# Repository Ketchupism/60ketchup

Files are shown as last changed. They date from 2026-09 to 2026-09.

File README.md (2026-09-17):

# 60ketchup
60% keyboard gasket-mount with hot-swaps

most effort-keyboard project I made

- 61 keys (number keys, no arrows keys)
- hot-swaps
- gasket-mount

I started with project somewhat weeks ago after finishing my first keyboard. There was so many improvements and changes I could of make if I made another keyboard. I tried to make a curved Alice, split wired keyboard. Unfortunately, I ended up with not many days to work on it and time was running out before the program ended. I had to edit my schematics and PCB to fit the new keyboard criteria. I spent the rest of the days just then working on the PCB and github. 

Overall, this project was fun and gave me opportunities to practice and learn using Fusion360 and KiCad and the general understanding of how keyboards are made. Learning how to create a keyboard and having a finished product that I was satisfied with was really nice. Some of the things that were a huge process or took a long time to learn / work on was reediting work to a new keyboard layout, tracing all my components, learning how to create a gasket mount that was stable, and creating my bill of materials list. My files are found in PCB and KiCad. 





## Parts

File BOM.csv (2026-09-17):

Item Number | Part Name | rough price(CAD) | Source
1 | Raspberry Pi Pico | $10 | https://www.aliexpress.com/item/1005012636772410.html
2 | Akko Bittersweet Switches | $40 | https://en.akkogear.com/product/bittersweet-switch-lubed/?wmc-currency=CAD
3 | Keebox Poron Gasket Stripes | $17 | https://www.aliexpress.com/item/1005011981917436.html?curPageLogUid=iiTFOxfWYzAK
4 | Diodes 1N4148 | $3 | https://www.aliexpress.com/item/1005004103990376.html?curPageLogUid=qKCPQEb689cl
5 | PCB | $50 | no link and manufacturer is JLCPCB
6 | Keycaps | $45 | https://www.aliexpress.com/item/1005008964445396.html?curPageLogUid=tNXORQnz6FKv
7 | Pre-lubed stabilizers | $8 | https://www.aliexpress.com/item/1005010788206824.html?curPageLogUid=R08arJvPWrKm
8 | TOTAL | $173CAD (~130USD) | N/A

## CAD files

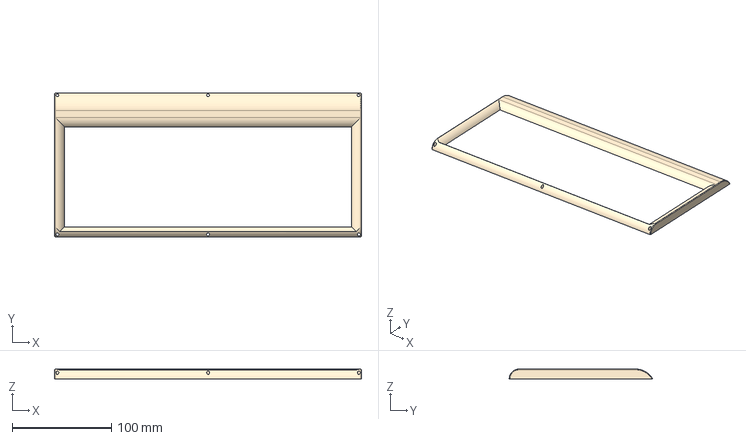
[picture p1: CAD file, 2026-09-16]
CAD/top_case.step
310.0 x 145.0 x 10.0 mm

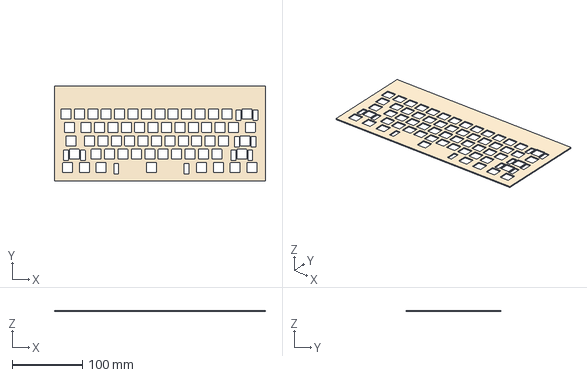
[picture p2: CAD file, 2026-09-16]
CAD/plate.step
300.0 x 135.0 x 1.50 mm

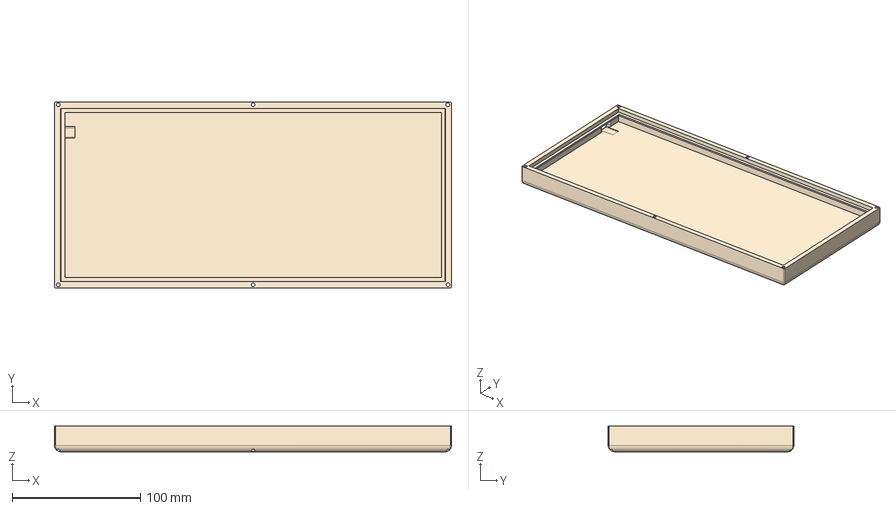
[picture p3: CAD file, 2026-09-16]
CAD/bottom_case.step
310.0 x 145.0 x 20.0 mm

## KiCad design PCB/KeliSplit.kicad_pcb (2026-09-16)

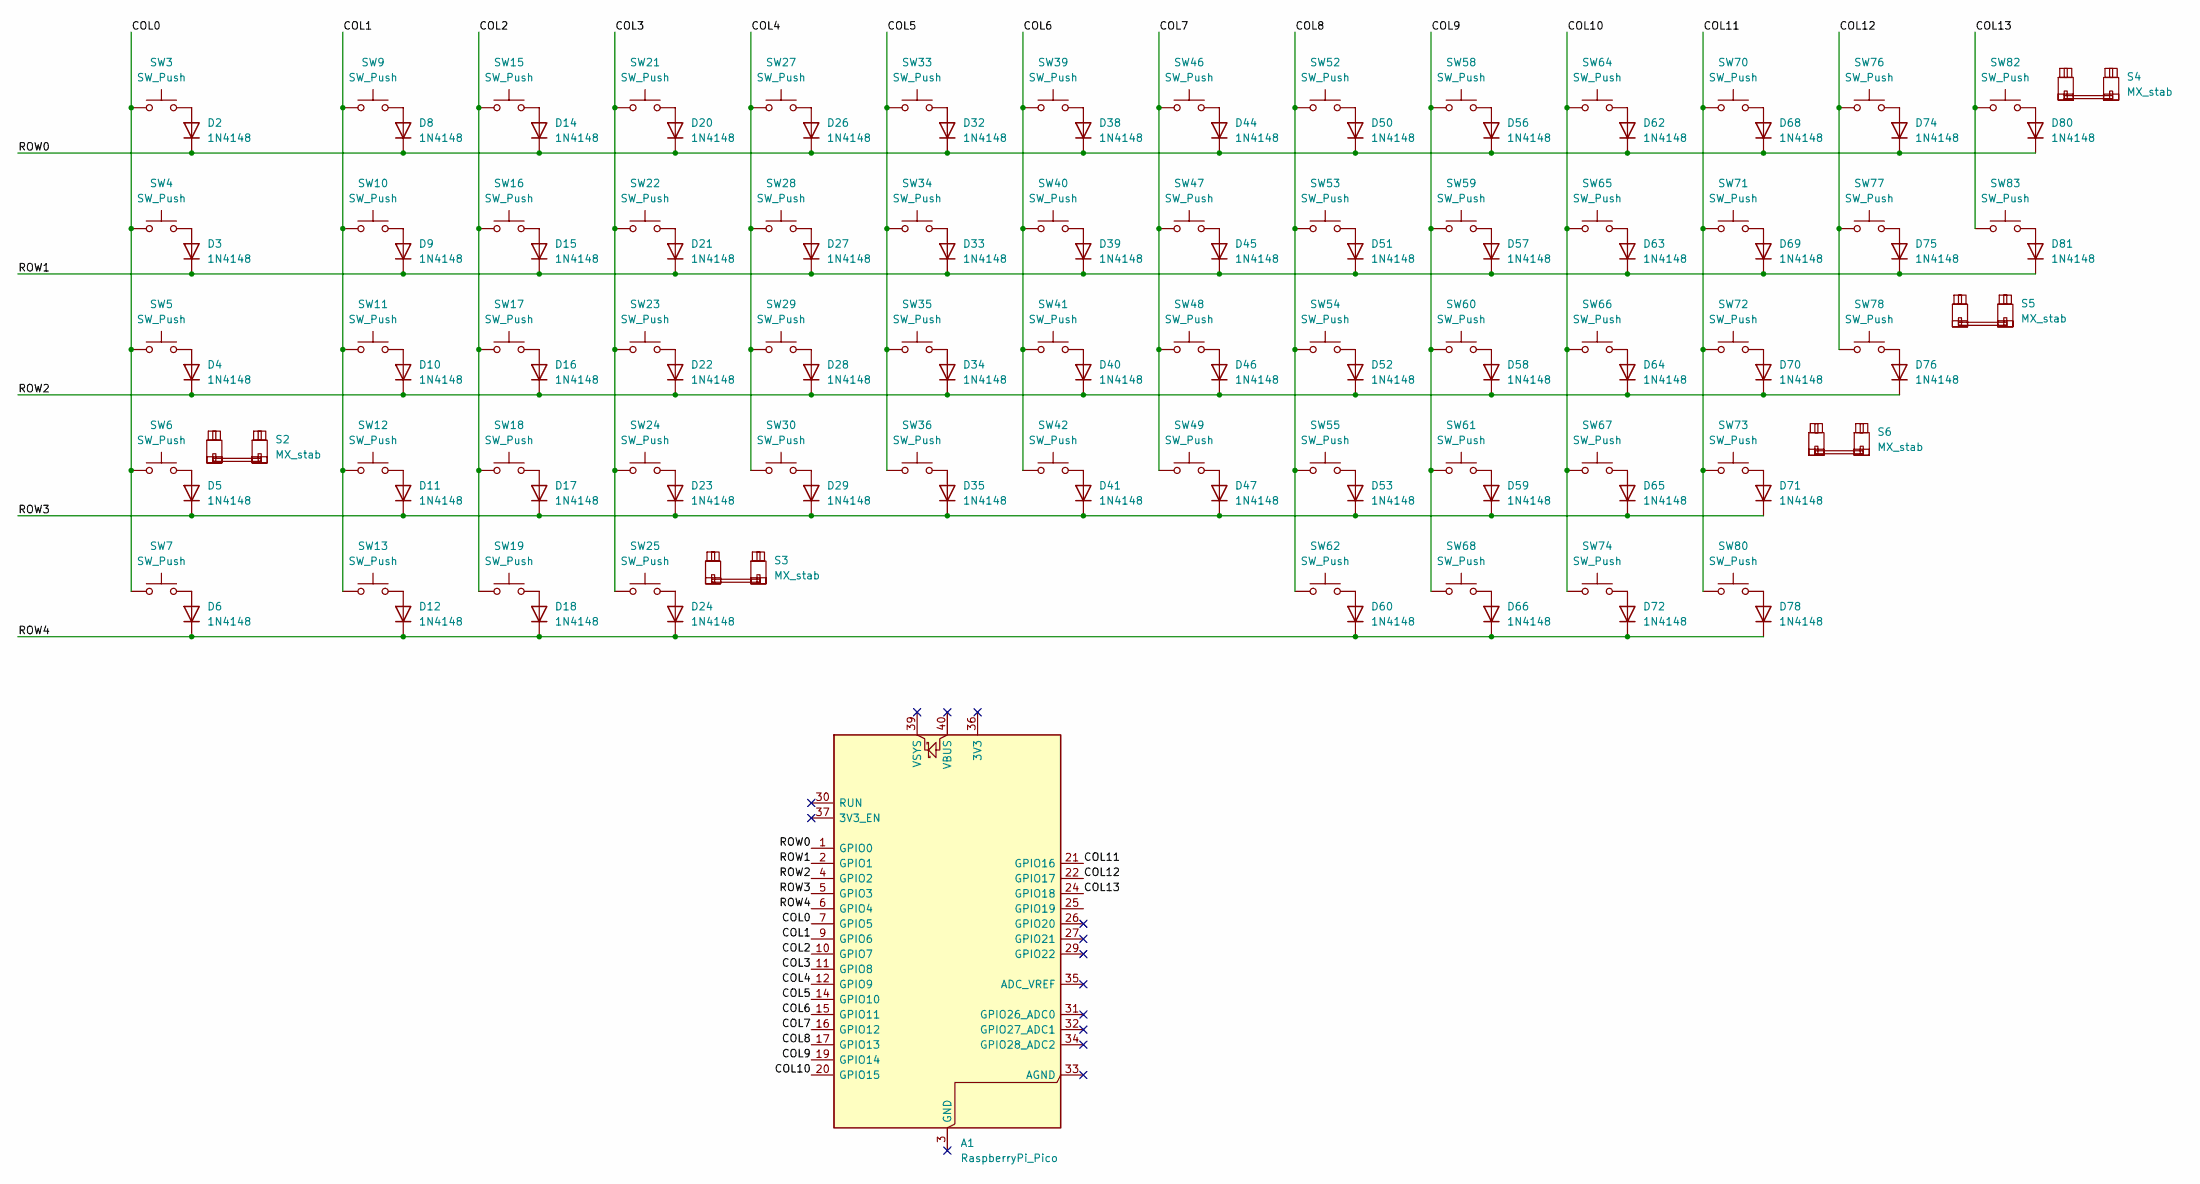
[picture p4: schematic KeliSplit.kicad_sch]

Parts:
A1: RaspberryPi_Pico; RaspberryPi_Pico_Common_THT
D2, D3, D4, D5, D6, D8, D9, D10, D11, D12, D14, D15, D16, D17, D18, D20, D21, D22, D23, D24, D26, D27, D28, D29, D32, D33, D34, D35, D38, D39, D40, D41, D44, D45, D46, D47, D50, D51, D52, D53, D56, D57, D58, D59, D60, D62, D63, D64, D65, D66, D68, D69, D70, D71, D72, D74, D75, D76, D78, D80, D81: 1N4148; D_DO-35_SOD27_P7.62mm_Horizontal
S2, S5: MX_stab; STAB_MX_P_2.25u
S3: MX_stab; STAB_MX_P_6.25u
S4: MX_stab; STAB_MX_P_2u
S6: MX_stab; STAB_MX_P_2.75u
SW3, SW6, SW9, SW10, SW11, SW12, SW15, SW16, SW17, SW18, SW21, SW22, SW23, SW24, SW25, SW27, SW28, SW29, SW30, SW33, SW34, SW35, SW36, SW39, SW40, SW41, SW42, SW46, SW47, SW48, SW49, SW52, SW53, SW54, SW55, SW58, SW59, SW60, SW61, SW64, SW65, SW66, SW67, SW70, SW71, SW72, SW73, SW76, SW77, SW78, SW82: SW_Push; SW_MX_HS_CPG151101S11_1u
SW4, SW83: SW_Push; SW_MX_HS_CPG151101S11_1.5u
SW5: SW_Push; SW_MX_HS_CPG151101S11_1.75u
SW7, SW13, SW19, SW62, SW68, SW74, SW80: SW_Push; SW_MX_HS_CPG151101S11_1.25u

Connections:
/COL0: A1.7 (GPIO5), SW3.1, SW4.1, SW5.1, SW6.1, SW7.1
/COL1: A1.9 (GPIO6), SW9.1, SW10.1, SW11.1, SW12.1, SW13.1
/COL2: A1.10 (GPIO7), SW15.1, SW16.1, SW17.1, SW18.1, SW19.1
/COL3: A1.11 (GPIO8), SW21.1, SW22.1, SW23.1, SW24.1, SW25.1
/COL4: A1.12 (GPIO9), SW27.1, SW28.1, SW29.1, SW30.1
/COL5: A1.14 (GPIO10), SW33.1, SW34.1, SW35.1, SW36.1
/COL6: A1.15 (GPIO11), SW39.1, SW40.1, SW41.1, SW42.1
/COL7: A1.16 (GPIO12), SW46.1, SW47.1, SW48.1, SW49.1
/COL8: A1.17 (GPIO13), SW52.1, SW53.1, SW54.1, SW55.1, SW62.1
/COL9: A1.19 (GPIO14), SW58.1, SW59.1, SW60.1, SW61.1, SW68.1
/COL10: A1.20 (GPIO15), SW64.1, SW65.1, SW66.1, SW67.1, SW74.1
/COL11: A1.21 (GPIO16), SW70.1, SW71.1, SW72.1, SW73.1, SW80.1
/COL12: A1.22 (GPIO17), SW76.1, SW77.1, SW78.1
/COL13: A1.24 (GPIO18), SW82.1, SW83.1
/ROW0: A1.1 (GPIO0), D2.1 (K), D8.1 (K), D14.1 (K), D20.1 (K), D26.1 (K), D32.1 (K), D38.1 (K), D44.1 (K), D50.1 (K), D56.1 (K), D62.1 (K), D68.1 (K), D74.1 (K), D80.1 (K)
/ROW1: A1.2 (GPIO1), D3.1 (K), D9.1 (K), D15.1 (K), D21.1 (K), D27.1 (K), D33.1 (K), D39.1 (K), D45.1 (K), D51.1 (K), D57.1 (K), D63.1 (K), D69.1 (K), D75.1 (K), D81.1 (K)
/ROW2: A1.4 (GPIO2), D4.1 (K), D10.1 (K), D16.1 (K), D22.1 (K), D28.1 (K), D34.1 (K), D40.1 (K), D46.1 (K), D52.1 (K), D58.1 (K), D64.1 (K), D70.1 (K), D76.1 (K)
/ROW3: A1.5 (GPIO3), D5.1 (K), D11.1 (K), D17.1 (K), D23.1 (K), D29.1 (K), D35.1 (K), D41.1 (K), D47.1 (K), D53.1 (K), D59.1 (K), D65.1 (K), D71.1 (K)
/ROW4: A1.6 (GPIO4), D6.1 (K), D12.1 (K), D18.1 (K), D24.1 (K), D60.1 (K), D66.1 (K), D72.1 (K), D78.1 (K)
unnamed: D2.2 (A), SW3.2
unnamed: D3.2 (A), SW4.2
unnamed: D4.2 (A), SW5.2
unnamed: D5.2 (A), SW6.2
unnamed: D6.2 (A), SW7.2
unnamed: D8.2 (A), SW9.2
unnamed: D9.2 (A), SW10.2
unnamed: D10.2 (A), SW11.2
unnamed: D11.2 (A), SW12.2
unnamed: D12.2 (A), SW13.2
unnamed: D14.2 (A), SW15.2
unnamed: D15.2 (A), SW16.2
unnamed: D16.2 (A), SW17.2
unnamed: D17.2 (A), SW18.2
unnamed: D18.2 (A), SW19.2
unnamed: D20.2 (A), SW21.2
unnamed: D21.2 (A), SW22.2
unnamed: D22.2 (A), SW23.2
unnamed: D23.2 (A), SW24.2
unnamed: D24.2 (A), SW25.2
unnamed: D26.2 (A), SW27.2
unnamed: D27.2 (A), SW28.2
unnamed: D28.2 (A), SW29.2
unnamed: D29.2 (A), SW30.2
unnamed: D32.2 (A), SW33.2
unnamed: D33.2 (A), SW34.2
unnamed: D34.2 (A), SW35.2
unnamed: D35.2 (A), SW36.2
unnamed: D38.2 (A), SW39.2
unnamed: D39.2 (A), SW40.2
unnamed: D40.2 (A), SW41.2
unnamed: D41.2 (A), SW42.2
unnamed: D44.2 (A), SW46.2
unnamed: D45.2 (A), SW47.2
unnamed: D46.2 (A), SW48.2
unnamed: D47.2 (A), SW49.2
unnamed: D50.2 (A), SW52.2
unnamed: D51.2 (A), SW53.2
unnamed: D52.2 (A), SW54.2
unnamed: D53.2 (A), SW55.2
unnamed: D56.2 (A), SW58.2
unnamed: D57.2 (A), SW59.2
unnamed: D58.2 (A), SW60.2
unnamed: D59.2 (A), SW61.2
unnamed: D60.2 (A), SW62.2
unnamed: D62.2 (A), SW64.2
unnamed: D63.2 (A), SW65.2
unnamed: D64.2 (A), SW66.2
unnamed: D65.2 (A), SW67.2
unnamed: D66.2 (A), SW68.2
unnamed: D68.2 (A), SW70.2
unnamed: D69.2 (A), SW71.2
unnamed: D70.2 (A), SW72.2
unnamed: D71.2 (A), SW73.2
unnamed: D72.2 (A), SW74.2
unnamed: D74.2 (A), SW76.2
unnamed: D75.2 (A), SW77.2
unnamed: D76.2 (A), SW78.2
unnamed: D78.2 (A), SW80.2
unnamed: D80.2 (A), SW82.2
unnamed: D81.2 (A), SW83.2

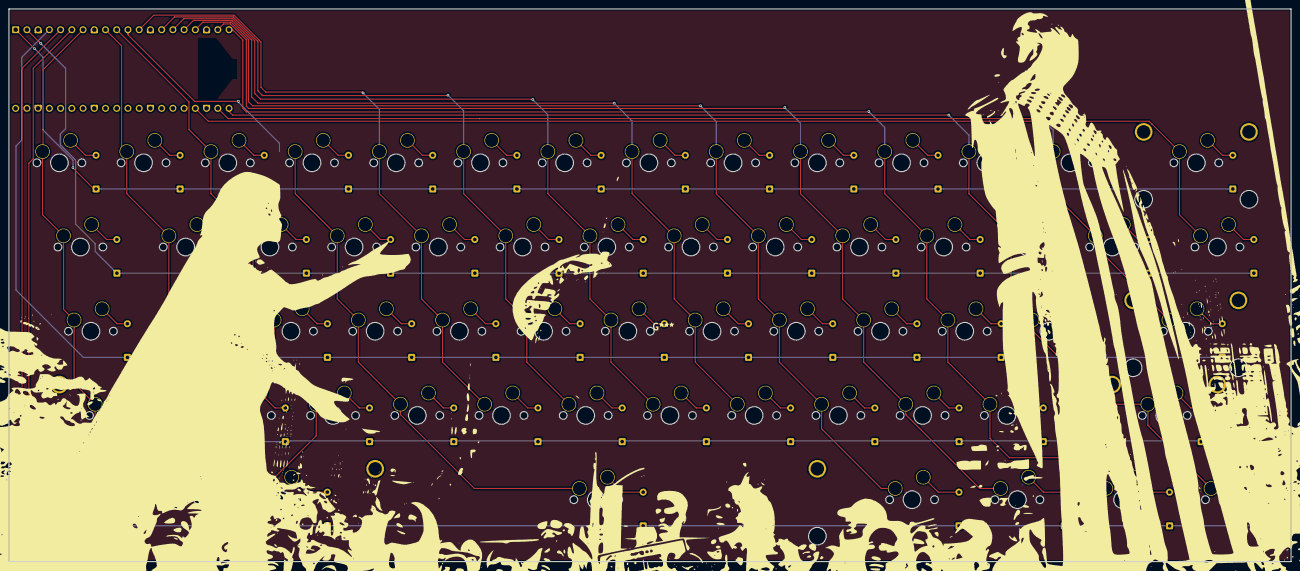
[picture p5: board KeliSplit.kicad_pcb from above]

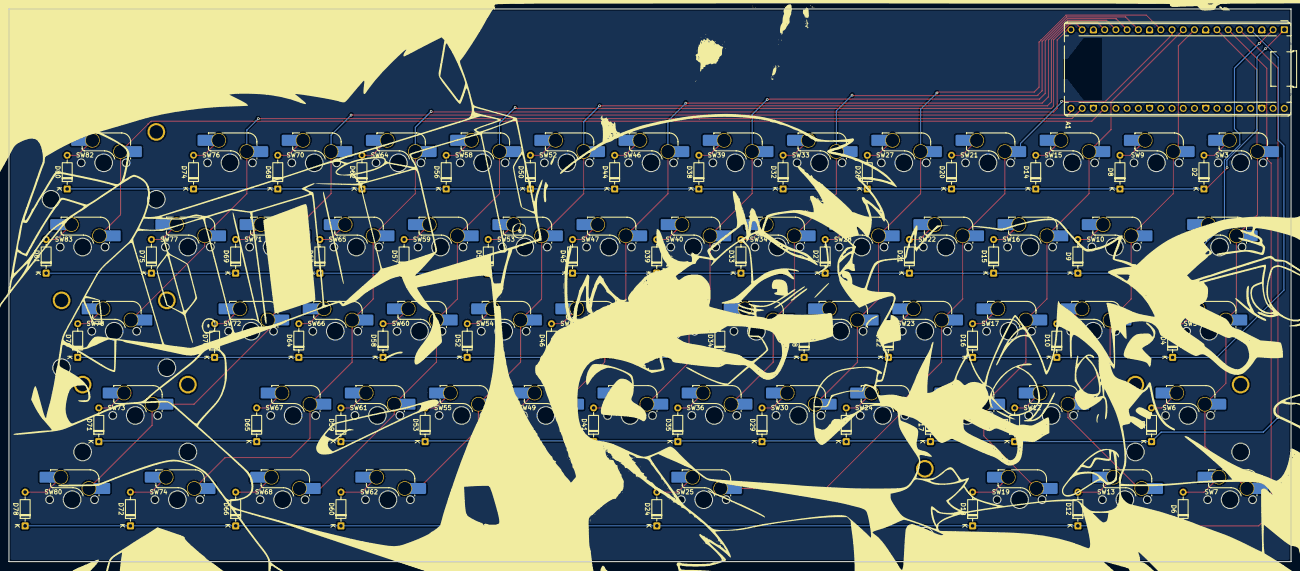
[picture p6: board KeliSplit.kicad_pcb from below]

Board: 2 copper layers, 290.0 x 125.0 mm, 128 parts (123 on the bottom side), 80 nets.

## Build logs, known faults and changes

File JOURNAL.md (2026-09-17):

# Designing layout 
- Sun Aug 29th
- 1.5 hr

I spent time planning out what type of keyboard I want, features to implement, and the layout of the keys. 
I've decided I wanted features of a split-wired keyboard, row staggering, Alice curved, extra keys for shortcuts, gasket mount with 3 layers, mousebites on PCB, and a foldable keyboard stand.
I'm thinking of implementing LEDS, Hot-swaps, a keyboard strap, PETG instead of PLA, and some other aesthetics.
Some things I want to change and work on from my previous keyboard design are: Use less PCB space, use less space for the keyboard on unnecessary things, and don't add extra colours / designs on the top / bottom case. These reasons are because of mainly cost, aesthetics and looks, and just in general how useless to is to have a bigger keyboard.



In this photo, I sketched out what the layout of my keys should be like. I also included a rotary encoder in the top left for probably brightness or volume. Afterwards, I wanted to switch to a curved Alice keyboard instead of a original Alice.


These are the two types side by side. 

----------------------------------------------------------------------------------------------------------------------------------------------------------------------------------------
# Designing Schematics
- Tue Sep 1 
- 3 hr

When making schematics I had to download marbastlib and panelization.pretty for 3d models and footprints. These libraries were used for switches, stabilizers, rotary encoder switch, and mousebites. Afterwards, I started to work on symbols and traces. Overall, designing schematics was not difficult, but just time-consuming because of designing the matrix for the switches and then fixing bugs in the Electric Rules Checker in Inspect tab. 

Working on the TRRS Jack (an audio port) as my interconnect cable, it was overall easy to add into as there only 4 points: Tip, Ring, Ring, Sleeve. Or known as Ground, VCC (5V or 3.3V), SERIAL as a Net Label, then Ground. Here's a picture of the microcontroller and TRRS Jack.


Here's a picture of the left side of the keyboard


Right side


----------------------------------------------------------------------------------------------------------------------------------------------------------------------------------------
# Fixing Schematics + Assigning Footprints
 - Fri Sep 4
 - 1.5 hr

 I spent time after the last post to assigning footprints to the symbols and fixing schematic bugs. In the matrix, I fixed one switch by pushing it up a row because in the layout it was supposed to be one of the arrow keys, instead it was on an empty space.


Afterwards, I edited the TRRS Jack symbol pins from S, R1, R2, T, to 4, 3, 2, 1. The reason I did this was because when assigning footprints and updating PCB from Schematics, it gave me a huge amount of errors + warnings about the pins from the footprints and schematics being different. All I did was go into symbol editor for both TRRS Jacks and switched the pins. 


The footprint in PCB:



When finished, I just assigned all the footprints to the symbols. 

RaspberryPi_Pico - Module:RaspberryPi_Pico_Common_THT, 

Mousebite - Panelization.pretty-master:mouse-bite-5mm-slot, 

1N4148 - Diode_THT:D_DO-35_SOD27_P7.62mm_Horizontal, 

AudioJack4 - Keebio-Parts.pretty-master:TRRS-PJ-320A,

MX_stab - PCM_marbastlib-mx:STAB_MX_2u, 

RotaryEncoder_Switch - Rotary_Encoder:RotaryEncoder_Alps_EC11E-Switch_Vertical_H20mm, 

SW_Push - Button_Switch_Keyoard:SW_Cherry_MX_1.00u_PCB

This is a picture of updating the PCB from schematics:


----------------------------------------------------------------------------------------------------------------------------------------------------------------------------------------
# Redesigning keyboard schematics + footprints + layout
 - Sat Sep 12
 - 2.5 hrs

The last few days I was busy with other work and school, where I don't think I don't have enough time to finish some portion of the keyboard. The switches on either side was incredibly hard to set up in PCB because when using coordinates and tilted switches, the x + y are different from 19.05 and I had no solution for setting up the ai03 plate generator. That's why this keyboard won't be a split alice keyboard. I'm gonna use a 60% gasket mount keyboard that is row staggered and is hot-swappable. This keyboard should be easy for me to complete by the end of this event. I also don't have any photos of me attempting to create the alice keyboard. When reediting the schematics & footprints, it wasn't hard because all I did was combine the two switch matrix's, remove TRRS Jack, and use only one raspberry Pi Pico for the entire keyboard. I then edited footprints by using marbastlib's hotswap footprints. 


This photo is a reference to what keyboard I'm trying to recreate. 


Here is the new switch matrix, where there is no F row, no arrow keys, and renamed net labels. 


One Raspberry Pi_Pico for 14 columns and 5 rows. removed GND and VCC. 



The footprint for Hot Swap switches

----------------------------------------------------------------------------------------------------------------------------------------------------------------------------------------
# Redesigning PCB, finalizing PCB, Adding 3d models, and exporting
 - Sat Sep 13
 - 3 hrs

 I spent the day basically just working on changing the PCB by updating the PCB from schematic changes, then reworked on organizing the switches. Afterwards, I placed diodes and traced everything together. I tried to compact the microcontroller as close to the switch matrix because I didn't want a large PCB, making it more difficult for the cost and size of the case I'm designing. It would also be aesthetically uncomfortable for a huge amount of space on the top. After adding the edge.cuts, I added some silkscreen pictures and drew filled zones for the PCB. I had to add in the 3d models for the switches because for some reason the footprint only came with the hotswaps. I also had to do the same process with the stabilizers. When finished with the PCB, I exported my gbr files and added in the KiCad files in the repository.

 Process of making the layout





3D model
Front



Back



----------------------------------------------------------------------------------------------------------------------------------------------------------------------------------------
 # Making gasket mount + Case, exporting into github 
 - Tue Sep 15
 - 4 hrs

 I have worked on the case and designing the gasket mount so the porons would fit properly with the plate. The first thing I did was export KiCad's 3d viewer model into a .stl file so I can use it for modelling my case. Afterwards, I went into ai03's plate generator and asked an ai for the format in 60% keyboards. I downloaded the DFX and uploaded to Fusion360's uploads for the plate. After exporting both the model and plate, I started working on the case. I made the thickness of the plate 1.5mm and descaled every side of the switches by -0.2mm because there may be issues for fitting because of 3d printing. I then worked on the gasket mount with first making the porons and then building off it. I got information of dimensions of the porons just asking ai and giving it the source to what i'm deciding to buy from. A problem I had was because the top part of my PCB was empty, I was worried about sagging when making the keyboard. I just ignored this as I would just use more porons or damping foam to hold the keyboard from sagging. the top and bottom case took me a while just because I had to constantly check if the porons if between the case and plate + PCB. I also added the USBC hole for the bottom case + 6 holes through top and bottom case for screwing in with heat-set inserts. After finalizing the entire case, I added fillets and made the colour beige (just so it's easy to differentiate from the other components. I then exported the cad files into Github for 3d printing and proof of work. Here's some photos:

Process of making the gasket mount case + the porons + PCB + plate





FINAL model showcase




----------------------------------------------------------------------------------------------------------------------------------------------------------------------------------------
 # Finishing, writing README.md, writing BOM.csm, and writing submission form for grant
 - Wed Sep 16
 - 1.5 hrs
it's finally finished

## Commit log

2026-09-14 Redesign PCB layout and finalize 3D models
    Updated the PCB design based on schematic changes, organized switches, placed diodes, and compacted the microcontroller. Added 3D models for switches and stabilizers, exported GBR files, and included KiCad files in the repository.
2026-09-16 cad files
    all necessary cad files for 3d printing the case
    [bottom_case.step, plate.step, top_case.step]
2026-09-16 Add journal entry for gasket mount case design
    Documented the process of designing and exporting a gasket mount case for a keyboard, including details on 3D modeling, material considerations, and final showcase images.
2026-09-17 Add BOM.csv with item structure
    [BOM.csv]
2026-09-17 Update BOM.csv with new items and prices
    [BOM.csv]
2026-09-17 Update BOM with new prices and items
    Updated item prices and added new items to the BOM.
    [BOM.csv]
2026-09-17 Document completion of tasks in JOURNAL.md
    Added a new entry about finishing tasks related to README.md, BOM.csm, and grant submission.
2026-09-17 Update PCB price and total cost in BOM.csv
    [BOM.csv]
